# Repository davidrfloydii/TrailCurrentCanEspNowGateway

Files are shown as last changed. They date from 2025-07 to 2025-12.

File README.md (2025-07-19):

# TrailCurrentCanEspNowGateway
This repository holds the code, schematics, and CAD files for an ESPNow gateway that relays CAN messages over the ESPNow protocol

# Overview
The reason to relay messages from the CAN Bus to ESPNow is to facilitate a remote device that can go into a tow vehicle. This allows for data being relayed over the CAN bus in a trailer to be displaye remotely and reliably in a vehicle.

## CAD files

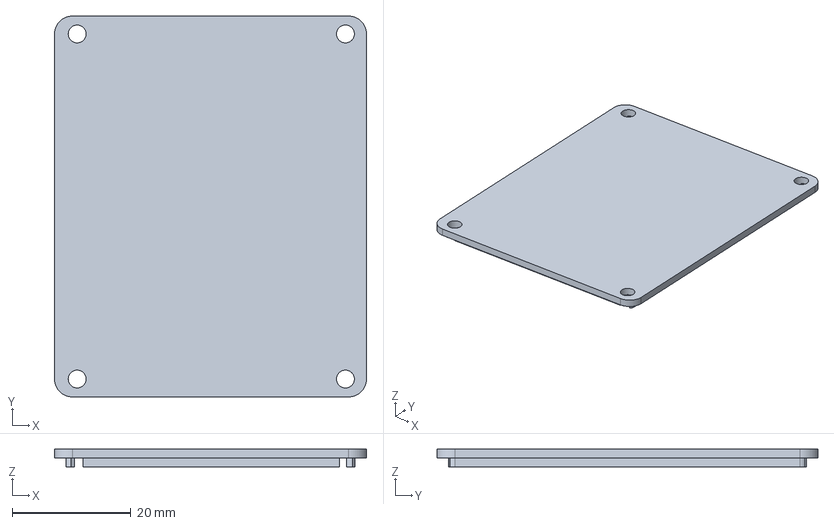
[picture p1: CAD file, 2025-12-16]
CAD/trailcurrent-can-to-espnow-gateway.FCStd
52.4 x 64.0 x 3.00 mm

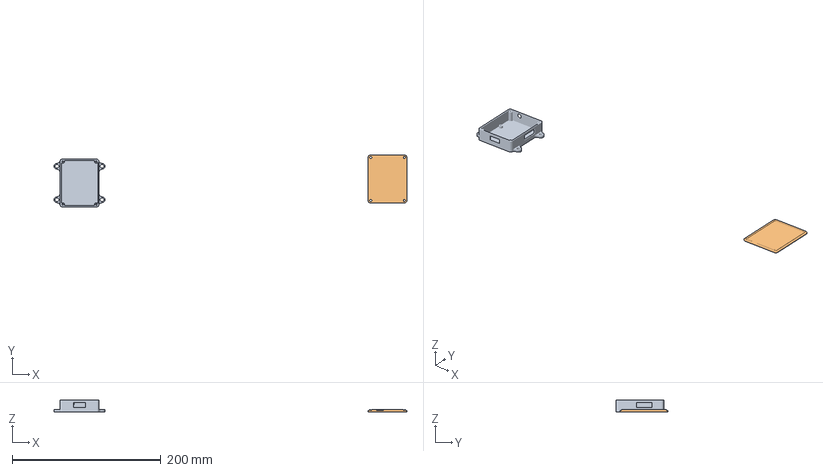
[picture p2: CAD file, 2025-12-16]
CAD/BodyCanToEspNowGatewayCase.3mf
474.1 x 69.4 x 15.5 mm
BodyCanToEspNowGatewayCaseBottomV1.stl
BodyCanToEspNowGatewayCaseCoverV1.stl

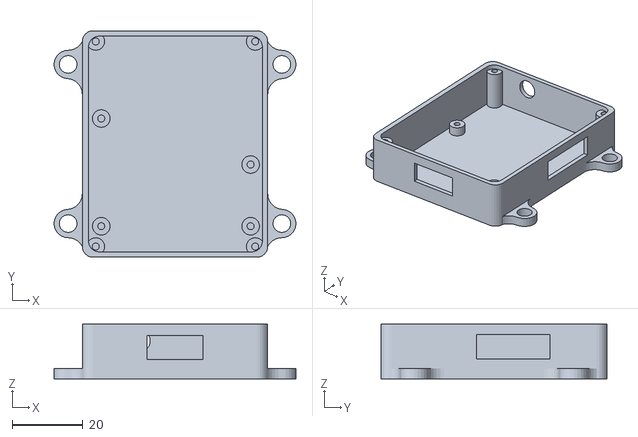
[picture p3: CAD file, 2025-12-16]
CAD/BodyCanToEspNowGatewayCaseBottomV1.stl
68.4 x 64.0 x 15.5

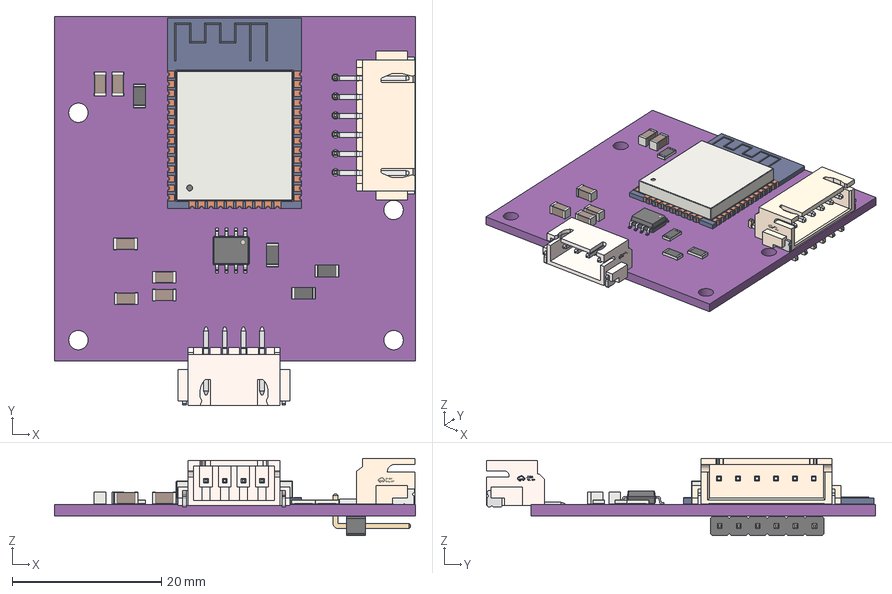
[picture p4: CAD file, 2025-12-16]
CAD/trailer-shunt-can-bus.step
48.4 x 52.1 x 10.3 mm
R_1206_3216Metric x 4
C_1206_3216Metric x 6
SOIC-8_3.9x4.9mm_P1.27mm
ESP32-WROOM-32
CONN-SMD_ZX-XH2.54-6PWT
CONN-SMD_4P-P2.50-WAFER-254W-4P
PinHeader_1x06_P2.54mm_Horizontal
trailecurrent-can-to-espnow-gateway_PCB

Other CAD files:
CAD/BodyCanToEspNowGatewayCaseCoverV1.stl

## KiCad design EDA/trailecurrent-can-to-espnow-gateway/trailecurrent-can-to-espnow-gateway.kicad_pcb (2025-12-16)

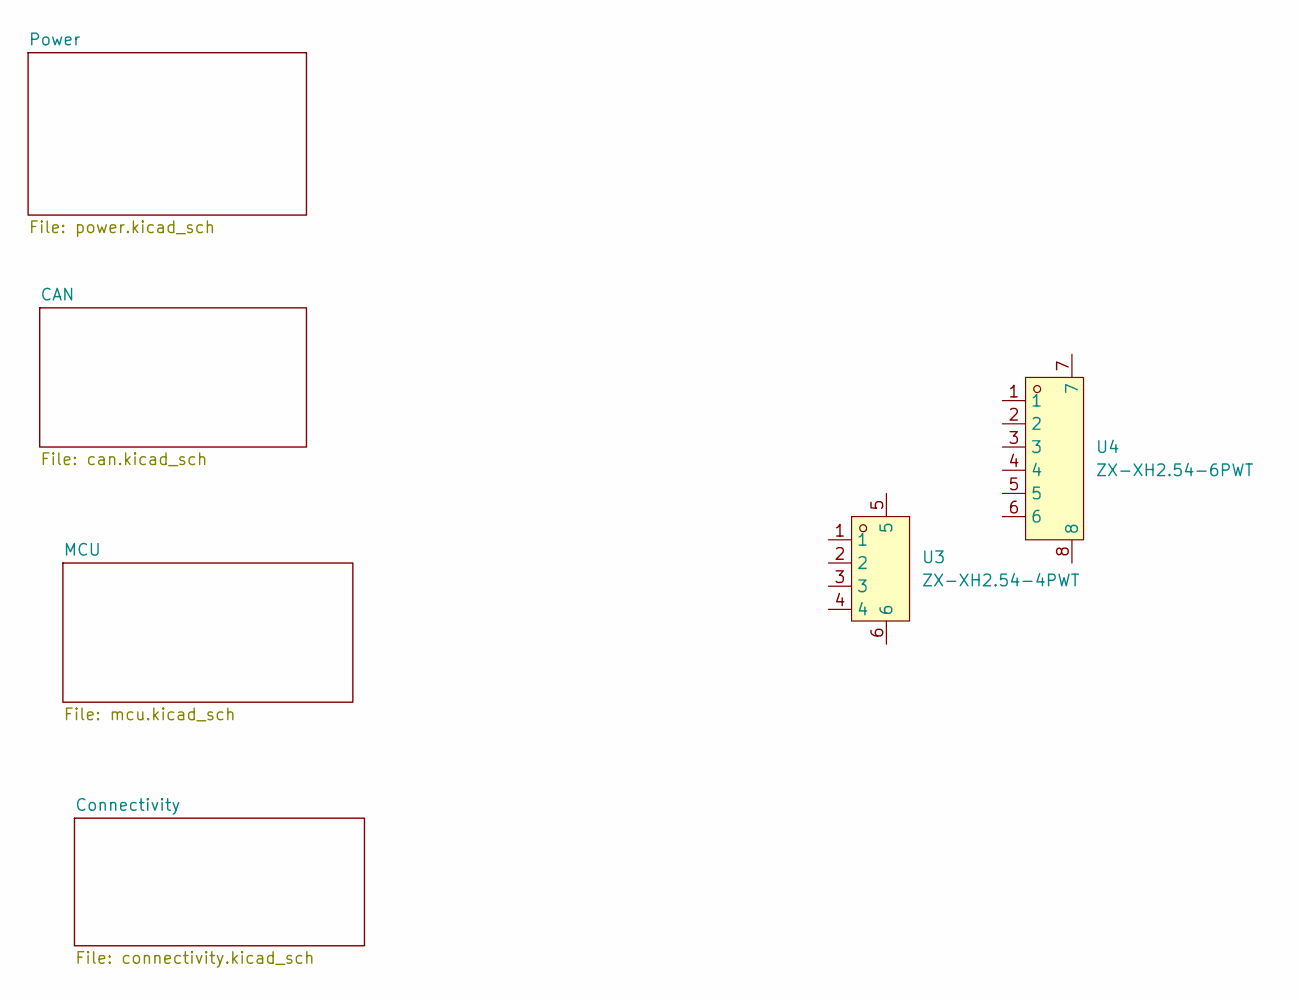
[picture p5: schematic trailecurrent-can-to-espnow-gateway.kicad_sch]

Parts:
U3: ZX-XH2.54-4PWT; CONN-SMD_4P-P2.50-WAFER-254W-4P; LCSC Part C7429673
U4: ZX-XH2.54-6PWT; CONN-SMD_ZX-XH2.54-6PWT; LCSC Part C7429675

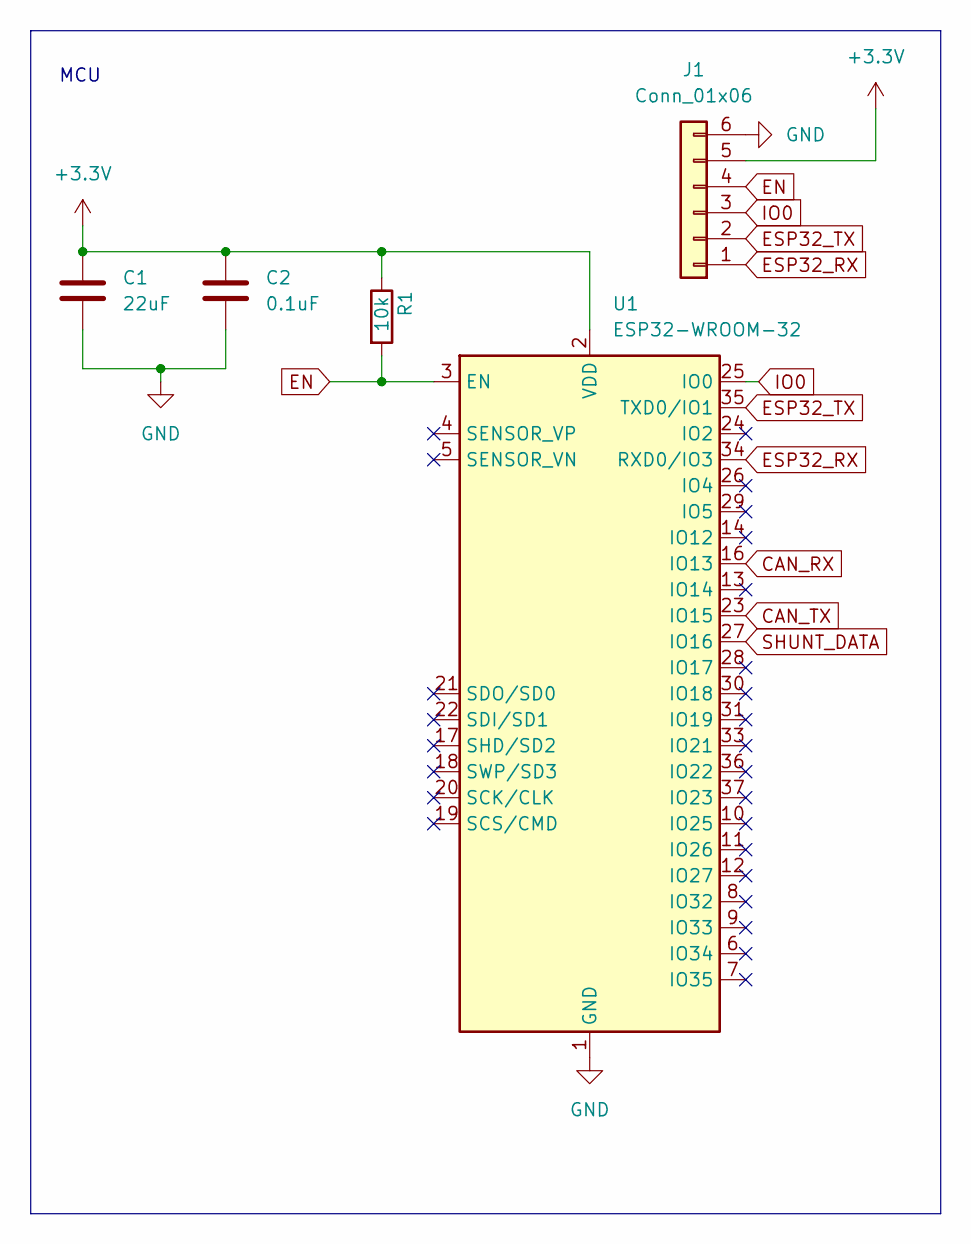
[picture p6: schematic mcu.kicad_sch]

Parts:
C1: 22uF; C_1206_3216Metric_Pad1.33x1.80mm_HandSolder
C2: 0.1uF; C_1206_3216Metric_Pad1.33x1.80mm_HandSolder
J1: Conn_01x06; PinHeader_1x06_P2.54mm_Horizontal
R1: 10k; R_1206_3216Metric_Pad1.30x1.75mm_HandSolder
U1: ESP32-WROOM-32

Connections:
+3.3V: C1.1, C2.1, J1.5, R1.1, U1.2 (VDD); also elsewhere on the board
CAN_RX: U1.16 (IO13); also elsewhere on the board
CAN_TX: U1.23 (IO15); also elsewhere on the board
EN: J1.4, R1.2, U1.3 (EN)
ESP32_RX: J1.1, U1.34 (RXD0/IO3)
ESP32_TX: J1.2, U1.35 (TXD0/IO1)
GND: C1.2, C2.2, J1.6, U1.1 (GND), U1.15 (GND), U1.38 (GND), U1.39 (GND); also elsewhere on the board
IO0: J1.3, U1.25 (IO0)
SHUNT_DATA: U1.27 (IO16); also elsewhere on the board

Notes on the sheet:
MCU

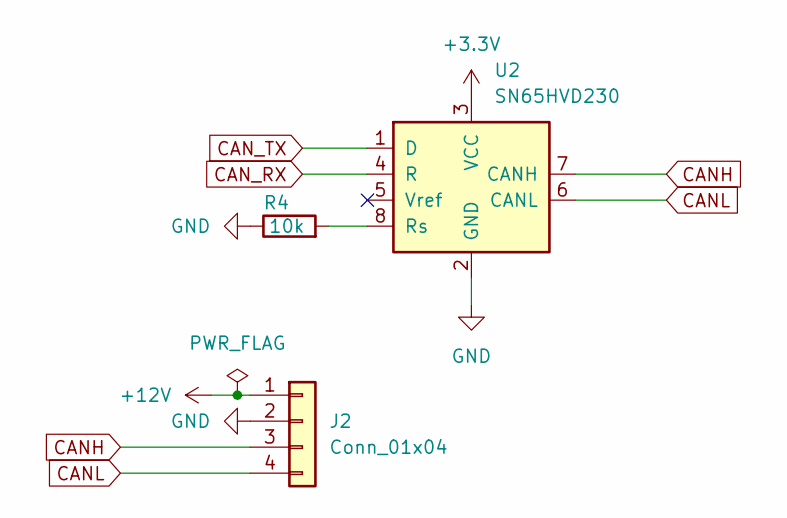
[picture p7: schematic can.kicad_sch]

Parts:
J2: Conn_01x04; CAN_PLUS_POWER
R4: 10k; R_1206_3216Metric_Pad1.30x1.75mm_HandSolder
U2: SN65HVD230; SOIC-8_3.9x4.9mm_P1.27mm

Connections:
+3.3V: U2.3 (VCC); also elsewhere on the board
+12V: J2.1; also elsewhere on the board
CANH: J2.3, U2.7 (CANH)
CANL: J2.4, U2.6 (CANL)
CAN_RX: U2.4 (R); also elsewhere on the board
CAN_TX: U2.1 (D); also elsewhere on the board
GND: J2.2, R4.1, U2.2 (GND); also elsewhere on the board
unnamed: R4.2, U2.8 (Rs)

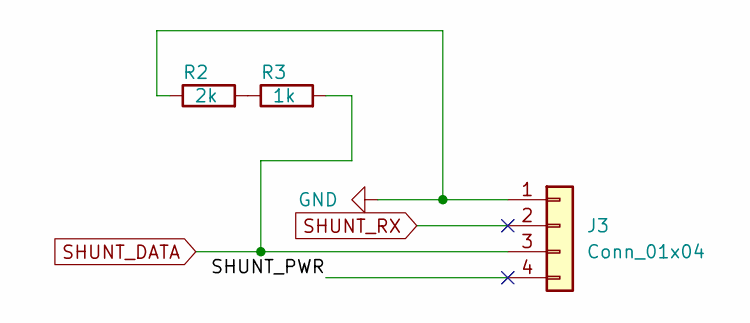
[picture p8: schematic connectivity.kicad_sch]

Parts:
J3: Conn_01x04; GenericPad_01x04
R2: 2k; R_1206_3216Metric_Pad1.30x1.75mm_HandSolder
R3: 1k; R_1206_3216Metric_Pad1.30x1.75mm_HandSolder

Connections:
/Connectivity/SHUNT_PWR: J3.4
GND: J3.1, R2.1; also elsewhere on the board
unnamed: R2.2, R3.1
SHUNT_DATA: J3.3, R3.2; also elsewhere on the board
SHUNT_RX: J3.2

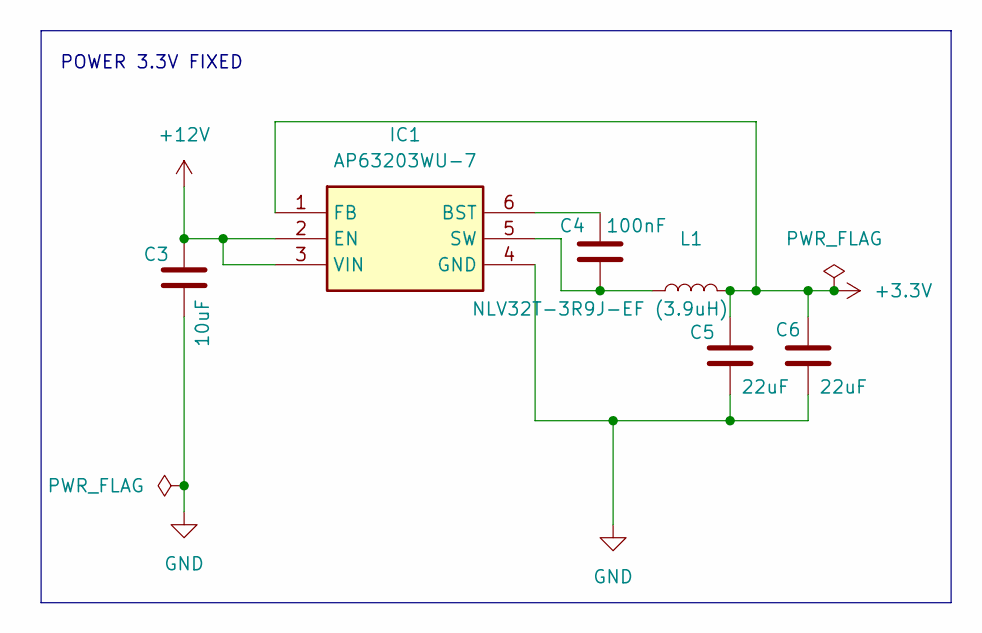
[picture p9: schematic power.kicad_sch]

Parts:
C3: 10uF; C_1206_3216Metric
C4: 100nF; C_1206_3216Metric
C5, C6: 22uF; C_1206_3216Metric_Pad1.33x1.80mm_HandSolder
IC1: AP63203WU-7; AP63203WU7; Mouser Part Number 621-AP63203WU-7
L1: NLV32T-3R9J-EF (3.9uH); NLV32T-3R9J-EF

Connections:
+3.3V: C5.1, C6.1, IC1.1 (FB), L1.2; also elsewhere on the board
+12V: C3.1, IC1.2 (EN), IC1.3 (VIN); also elsewhere on the board
GND: C3.2, C5.2, C6.2, IC1.4 (GND); also elsewhere on the board
unnamed: C4.1, IC1.6 (BST)
unnamed: C4.2, IC1.5 (SW), L1.1

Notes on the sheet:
POWER 3.3V FIXED

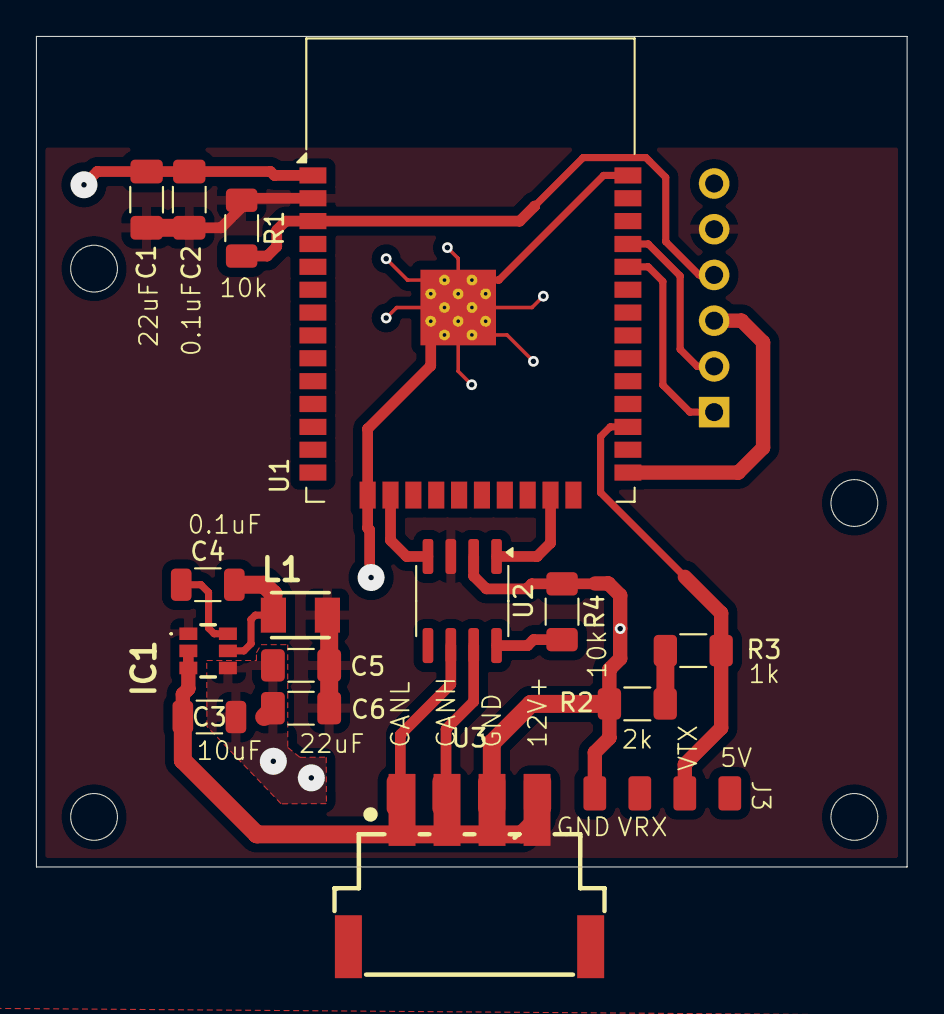
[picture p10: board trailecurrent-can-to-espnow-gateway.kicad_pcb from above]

Board: 2 copper layers, 48.4 x 46.1 mm, 18 parts (1 on the bottom side), 16 nets.

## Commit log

2025-07-19 Adding EDA files
    [trailcurrent-can-esp-now-gateway.kicad_pcb, trailcurrent-can-esp-now-gateway.kicad_sch]
2025-12-16 Updating case design and code is confirmed to be working.
    [BodyCanToEspNowGatewayCaseBottomV1.stl, can.kicad_sch, connectivity.kicad_sch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]
2025-12-16 Increased queue size and added CAD files and 3D print files
    [BodyCanToEspNowGatewayCase.3mf, BodyCanToEspNowGatewayCaseCoverV1.stl, trailcurrent-can-to-espnow-gateway.FCStd]
